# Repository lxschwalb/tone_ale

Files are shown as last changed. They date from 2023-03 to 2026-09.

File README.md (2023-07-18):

# Tone Ale
Reprogrammable rp2040 based guitar pedal with capacitive touch sensing. Some effects are toggled on and off by tapping on the pedal surface, others act as expression pedals by increasing and decreasing the pressure/surface area you apply to the pedal.

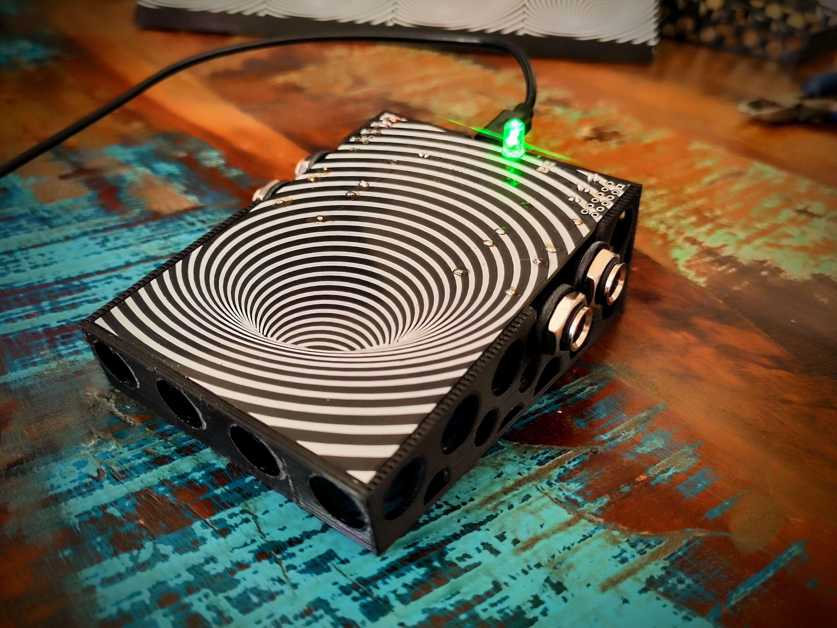
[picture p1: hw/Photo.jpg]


## Effects:
* audio interface
  * 2 input 2 output usb audio interface. Tap on pedal surface to mute/unmute it. LED indicates mute status. Only 48kHz 32bit audio supported.
* cabinet simulator
  * Guitar cabinet simulator using an impulse response.
* delay
  * Stereo digital delay. Each repeat is half the volume of the previous. Set feedback to false for only one repeat. Change delay buffer size for a different delay time. set it to an odd number for ping pong delay.
* fuzz
  * Simple fuzz. Turn on the gate for a tight velcro sound. Change the gain and clipping levels to taste.
* low pass filter
  * Always on low pass filter. Cuttoff frequency is determined by pressure applied to pedal. When not touching the pedal the cuttoff frequency should be higher than audible range so it is as if there is no filter.
* phaser
  * phaser effect with various parameters that can be tuned in code.
* rig
  * fuzz and cabinet simulator together in one effect which kind of gives the sound of a full guitar rig.
* sample player (amen beat)
  * sample starts playing when you place your foot on the pedal and stops when you take it away. It restarts from the beginning everytime. Increasing and decreasing the pressure/surface area changes the volume.
* sample rate reducer
  * By default the sample rate is 48kH and there is no aliasing. By stepping on the pedal you decrease the sample rate and introduce aliasing artifacts. The harder you press the more the sample rate drops.
* unstable noise generator
  * Unstable IIR filter. It chaotically generates weird sounds which are effected by the input in unpredictable ways.
* vibrato
  * pitch shifting vibrato
* wah
  * classic band pass filter wah sound. It engages when you step on the pedal and then you control the wah using pressure. As soon as you remove your foot it outputs the dry signal again.
* wavefolder
  * Similar to fuzz, except instead of clipping it folds the part of the signal above the threshold back down.

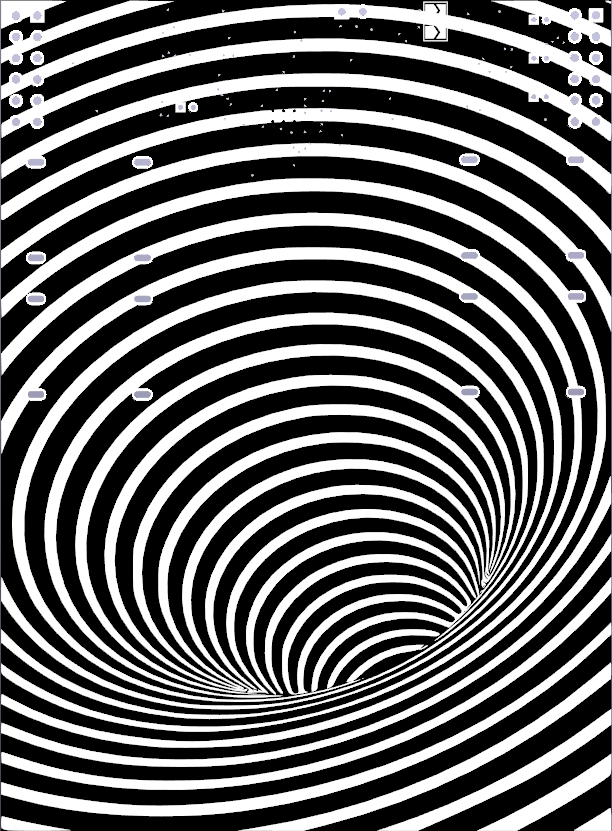
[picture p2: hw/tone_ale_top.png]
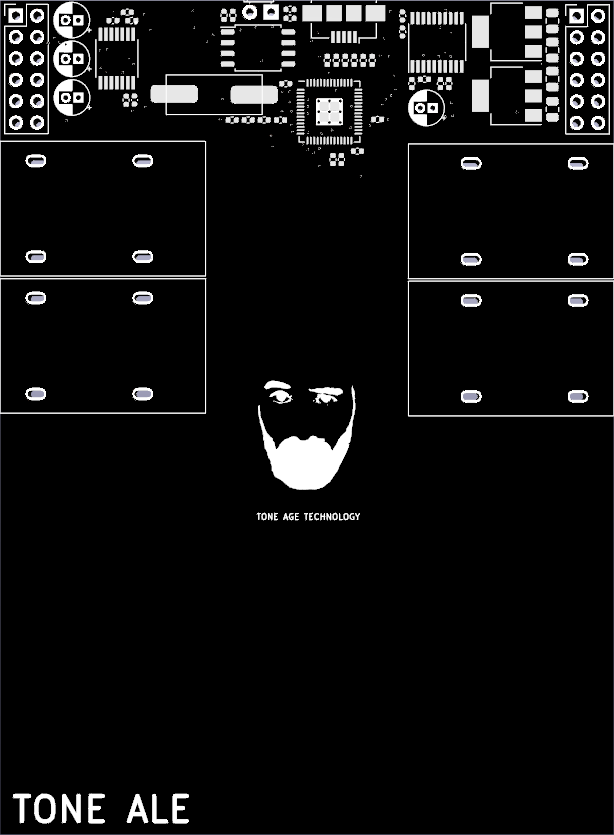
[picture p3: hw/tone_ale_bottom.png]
 

## Where to get one?
Everything necesary to build your own Tone Ale is available on this repository, but if you want to buy a fully assembled Pedal send an email to toneagetechnology@gmail.com. Profits are donated to effective charities.

Pedals will be sold for CHF125. In spirit of full transparency, I will share that my production cost per pedal is between CHF20 and CHF30 depending on a few varying factors. It would likely cost you more. It's cheaper for me since I'm producing it in bulk and already have a lot of the tools required. I will assume it's a fixed CHF25 and donate CHF100 for every pedal sold. This production cost does not include my time/labour, because that is done pro bono.

For questions about my charity selection process, motivation for doing this, or if you have a prefered charity you want payment for your pedal donated to, you can also email toneagetechnology@gmail.com.

## Upload new effect
You don't need to be able to develop or install special software to upload new effects. All you need is a usb port, cable, and something conductive (a piece of tin foil will to).

To upload new effects, connect the pedal to a computer with a usb cable, touch the part of the pcb shown in the image below with a piece of tin foil and drag it to the side as shown. Now the pedal shows up as a mass storage device. Just drag and drop the uf2 file(found in /compiled_effects) of the corresponding effect and you're all set to go.

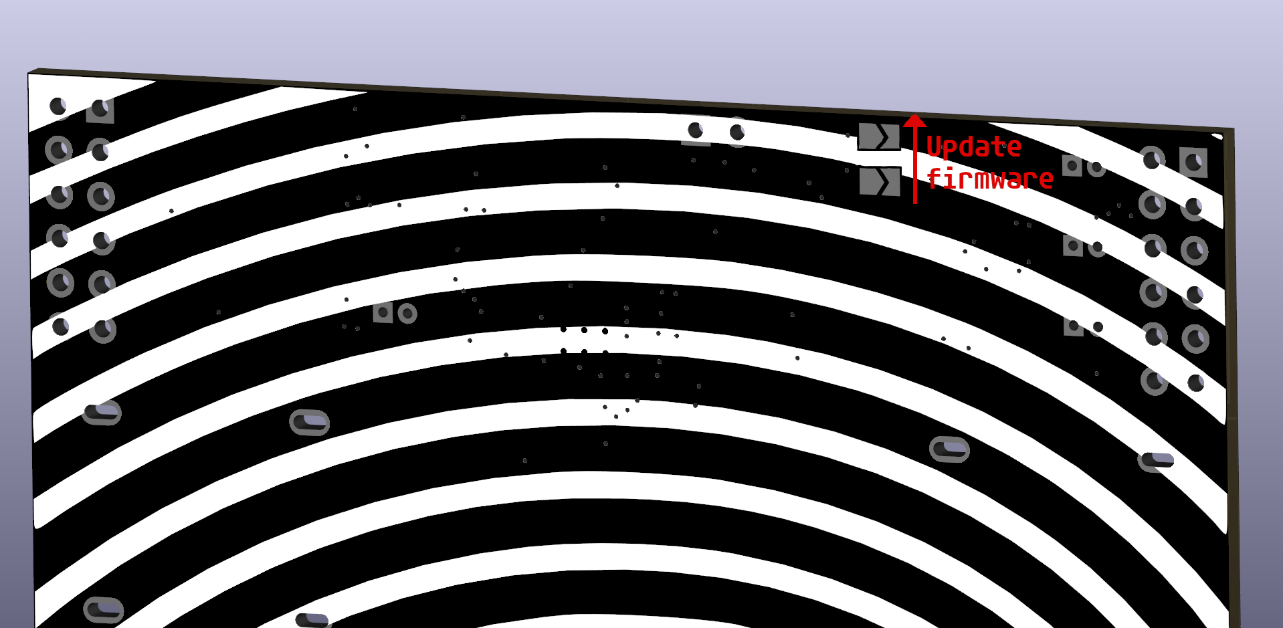
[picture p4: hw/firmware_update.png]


## Compile effects
Perhaps you want to alter some effects before uploading it onto the pedal. For example you might want to increase the gain of the fuzz. This would require recompiling the effect after the changes to the code have been made. Follow the steps below to recompile:

First set up the Pi Pico SDK according to [this guide](https://www.raspberrypi.com/documentation/microcontrollers/c_sdk.html#sdk-setup)

Open terminal in the main project folder (called tone_ale) and run the following commands:

`cp <pico_sdk_path>/external/pico_sdk_import.cmake .` (replace <pico_sdk_path> with wherever you set up the SDK)

`cd /build`

`cmake ..`

`make`

This will compile each effect and place it in "/build/<effect_name>/<effect_name>.uf2". This uf2 file can then directly be uploaded onto the pedal using the method descibed above

## Develop new effects
TODO explain this

## Pinout
The pinout is shown below.
* POT0, POT1, POT2 and POT3 can be programmed as analog inputs, so they can be used for adding potentiometers (knobs)
* GP0, GP1, GP2, GP3, GP4, GP5 and GP6 are general purpose digital input/output pins, so they can be used for many different things including LEDs, buttons, digitally communicating with external devices such as displays etc.
* If you want to chain multiple Tone Ale's together, you can reduce cost and improve fidelity by not putting DACs and ADCs between them and just directly connect their VBUS, GND, I2CV_CLK, I2CV_WS and connect the I2CV_OUT from the first pedal to the I2CV_IN of the second. You can chain many pedals together in this way (it's been tested up to 4). NB: Only the first pedal in the chain should have an PCM1808 soldered on, otherwise the I2CV_CLK and I2CV_WS will be driven by multiple sources. Alternatively you can run a different firmware on all pedals except the first one in the chain where the PCM1808 does not generate a clock. (TODO: explain how to do this)

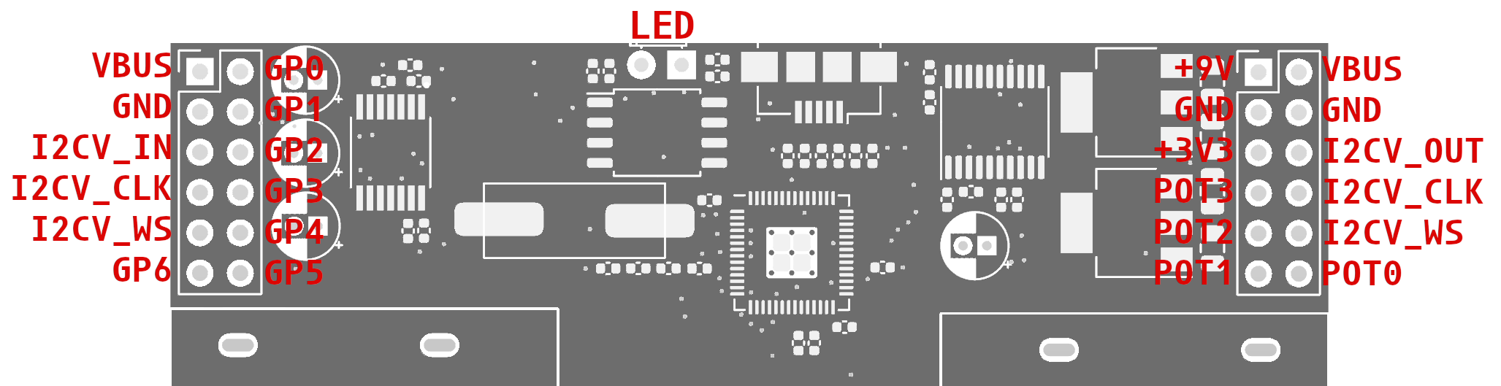
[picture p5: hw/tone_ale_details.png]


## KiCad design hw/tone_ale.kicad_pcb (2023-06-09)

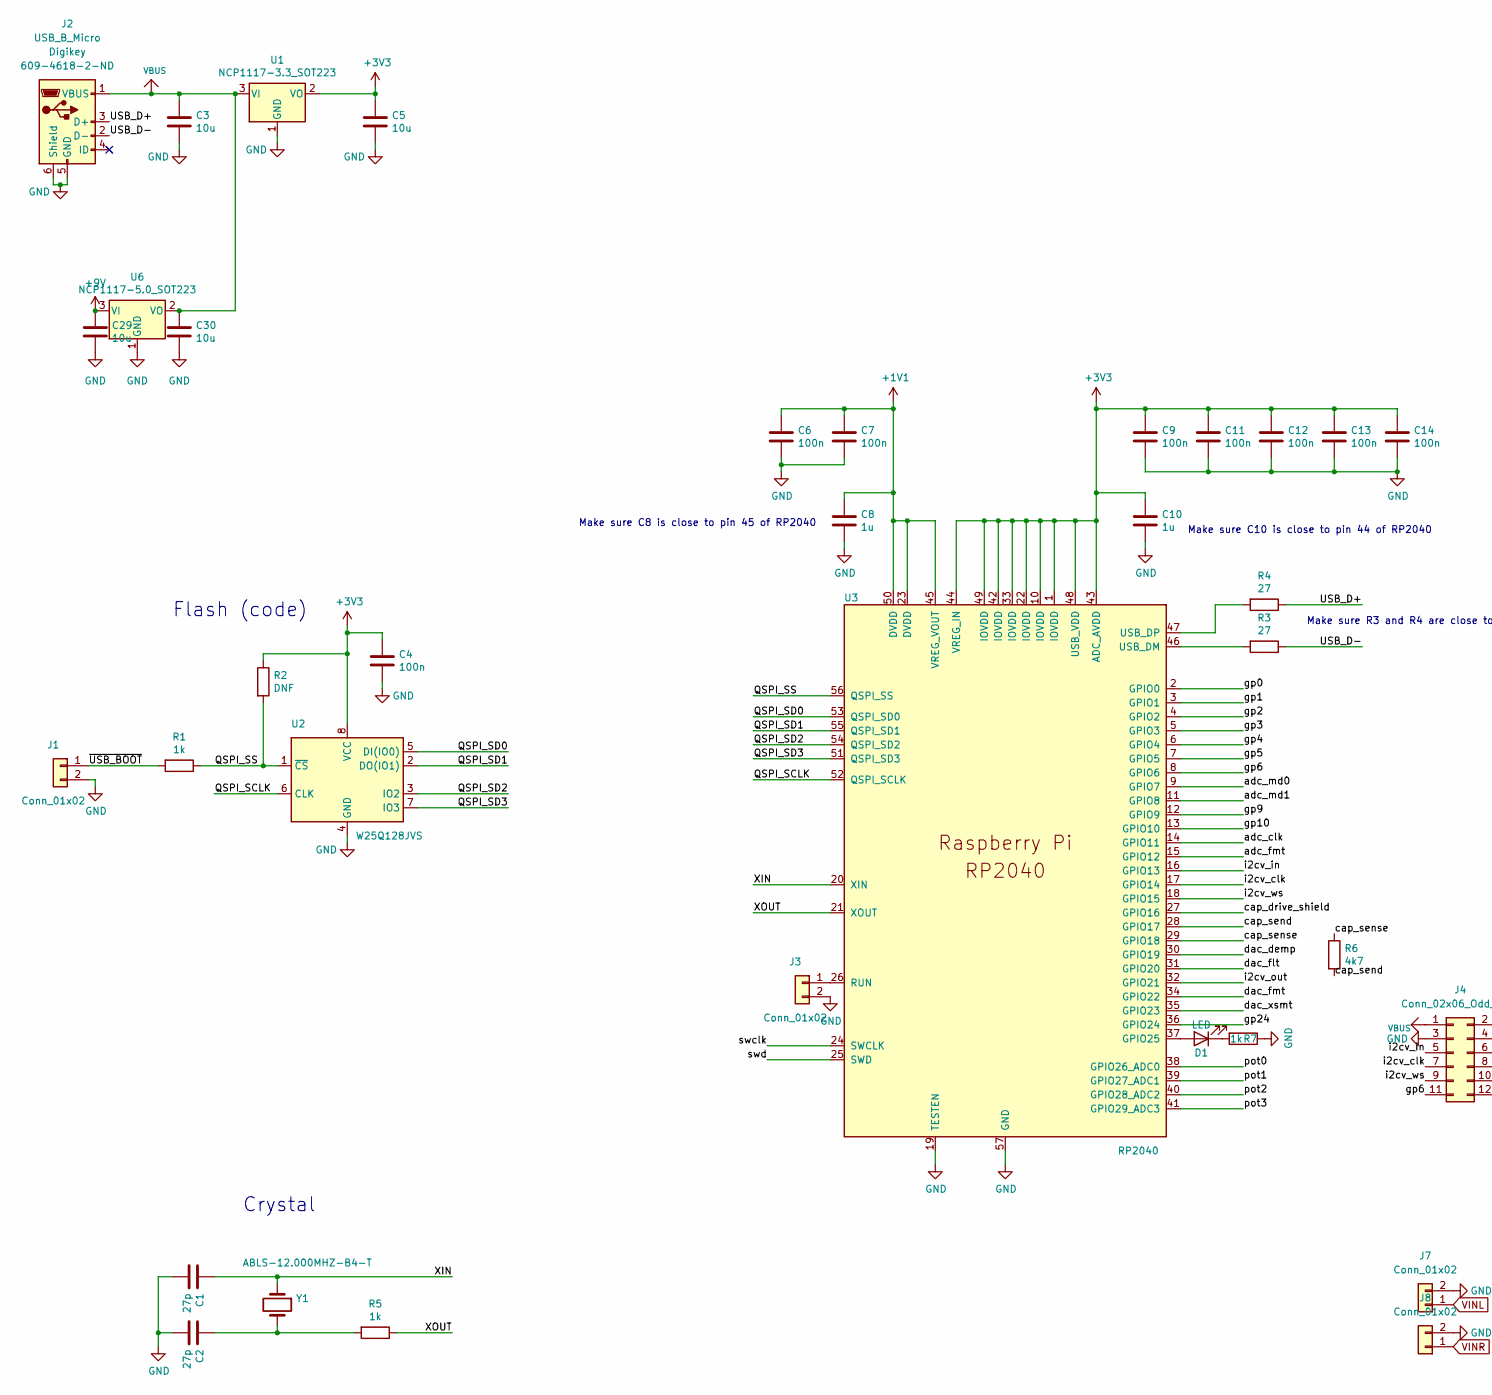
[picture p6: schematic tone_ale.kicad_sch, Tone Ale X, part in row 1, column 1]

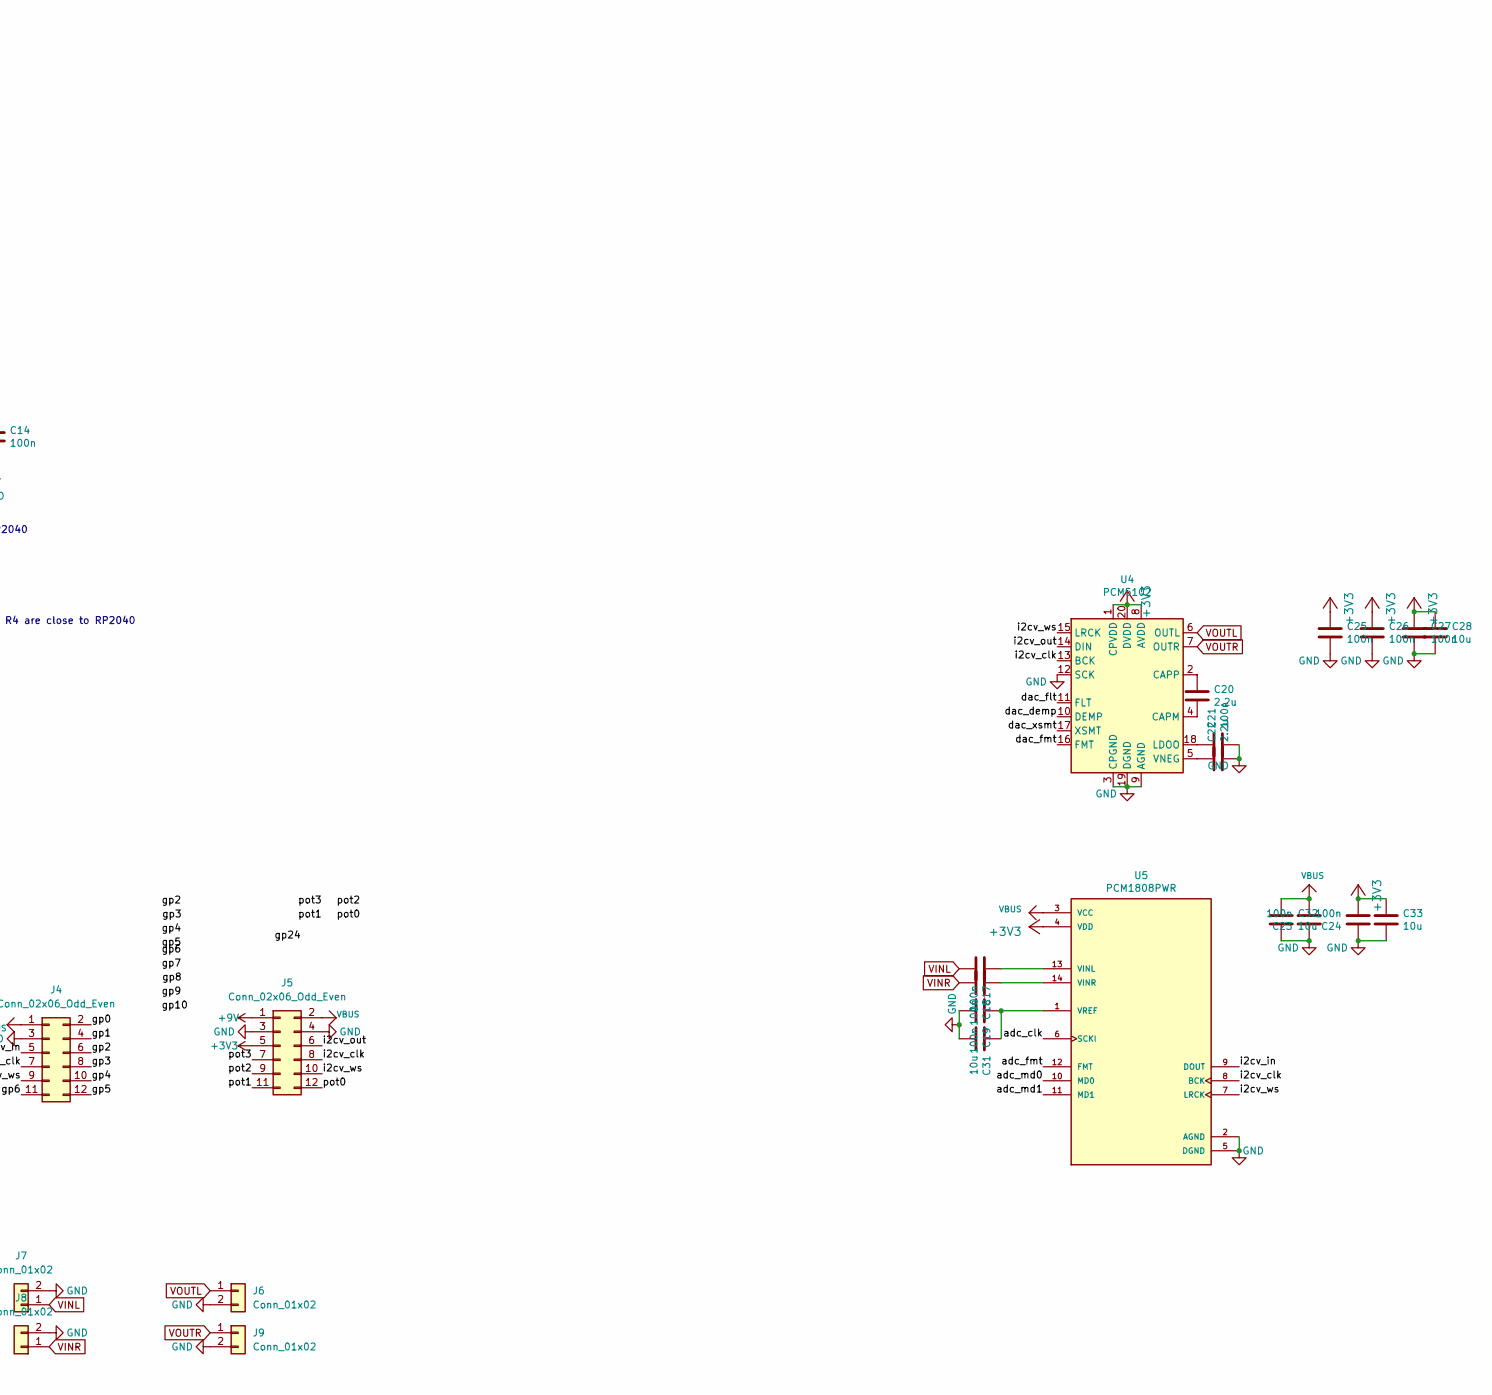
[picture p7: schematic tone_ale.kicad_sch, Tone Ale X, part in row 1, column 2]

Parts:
C1, C2: 27p; C_0402_1005Metric
C3, C5, C29, C30: 10u; C_0805_2012Metric
C4, C6, C7, C9, C11, C12, C13, C14, C17, C18, C19, C21, C23, C24, C25, C26, C27: 100n; C_0402_1005Metric
C8, C10: 1u; C_0402_1005Metric
C20, C22: 2.2u; C_0402_1005Metric
C28, C31, C32, C33: 10u; CP_Radial_D4.0mm_P1.50mm
D1: LED; LED_D3.0mm_Horizontal_O1.27mm_Z2.0mm
J1, J3: Conn_01x02; SolderJumper-2_P1.3mm_Open_TrianglePad1.0x1.5mm
J2: USB_B_Micro; USB_Micro-B_Amphenol_10104110_Horizontal
J4, J5: Conn_02x06_Odd_Even; PinHeader_2x06_P2.54mm_Vertical
J6, J7, J8, J9: Conn_01x02; acjm_mhdr
R1, R5, R7: 1k; C_0402_1005Metric
R2: DNF; C_0402_1005Metric
R3, R4: 27; C_0402_1005Metric
R6: 4k7; C_0402_1005Metric
U1: NCP1117-3.3_SOT223; SOT-223-3_TabPin2
U2: W25Q128JVS; SOIC-8_5.23x5.23mm_P1.27mm; Part Nr W25Q128JVSIMTR (digikey)
U3: RP2040; RP2040-QFN-56; Part Nr 2648-SC0914(13)TR-ND
U4: PCM5102; TSSOP-20_4.4x6.5mm_P0.65mm
U5: PCM1808PWR; SOP65P640X120-14N; PARTREV B
U6: NCP1117-5.0_SOT223; SOT-223-3_TabPin2
Y1: ABLS-12.000MHZ-B4-T; ABLS_crystal_12.7x04.7; Part Nr 535-10218-2-ND (digikey)

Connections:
+1V1: C6.1, C7.1, C8.1, U3.23 (DVDD), U3.45 (VREG_VOUT), U3.50 (DVDD)
+3V3: C4.1, C5.1, C9.1, C10.1, C11.1, C12.1, C13.1, C14.1, C24.2, C25.1, C26.1, C27.1, C28.1, C33.1, J5.5, R2.1, U1.2 (VO), U2.8 (VCC), U3.1 (IOVDD), U3.10 (IOVDD), U3.22 (IOVDD), U3.33 (IOVDD), U3.42 (IOVDD), U3.43 (ADC_AVDD), U3.44 (VREG_IN), U3.48 (USB_VDD), U3.49 (IOVDD), U4.1 (CPVDD), U4.8 (AVDD), U4.20 (DVDD), U5.4 (VDD)
+9V: C29.1, J5.1, U6.3 (VI)
/QSPI_SCLK: U2.6 (CLK), U3.52 (QSPI_SCLK)
/QSPI_SD0: U2.5 (DI(IO0)), U3.53 (QSPI_SD0)
/QSPI_SD1: U2.2 (DO(IO1)), U3.55 (QSPI_SD1)
/QSPI_SD2: U2.3 (IO2), U3.54 (QSPI_SD2)
/QSPI_SD3: U2.7 (IO3), U3.51 (QSPI_SD3)
/QSPI_SS: R1.1, R2.2, U2.1 (~CS), U3.56 (QSPI_SS)
/USB_D+: J2.3 (D+), R4.1
/USB_D-: J2.2 (D-), R3.1
/XIN: C1.1, U3.20 (XIN), Y1.1
/XOUT: R5.1, U3.21 (XOUT)
/adc_clk: U3.14 (GPIO11), U5.6 (SCKI)
/adc_fmt: U3.15 (GPIO12), U5.12 (FMT)
/adc_md0: U3.9 (GPIO7), U5.10 (MD0)
/adc_md1: U3.11 (GPIO8), U5.11 (MD1)
/cap_drive_shield: U3.27 (GPIO16)
/cap_send: R6.2, U3.28 (GPIO17)
/cap_sense: R6.1, U3.29 (GPIO18)
/dac_demp: U3.30 (GPIO19), U4.10 (DEMP)
/dac_flt: U3.31 (GPIO20), U4.11 (FLT)
/dac_fmt: U3.34 (GPIO22), U4.16 (FMT)
/dac_xsmt: U3.35 (GPIO23), U4.17 (XSMT)
/gp0: J4.2, U3.2 (GPIO0)
/gp1: J4.4, U3.3 (GPIO1)
/gp2: J4.6, U3.4 (GPIO2)
/gp3: J4.8, U3.5 (GPIO3)
/gp4: J4.10, U3.6 (GPIO4)
/gp5: J4.12, U3.7 (GPIO5)
/gp6: J4.11, U3.8 (GPIO6)
/gp9: U3.12 (GPIO9)
/gp10: U3.13 (GPIO10)
/gp24: U3.36 (GPIO24)
/i2cv_clk: J4.7, J5.8, U3.17 (GPIO14), U4.13 (BCK), U5.8 (BCK)
/i2cv_in: J4.5, U3.16 (GPIO13), U5.9 (DOUT)
/i2cv_out: J5.6, U3.32 (GPIO21), U4.14 (DIN)
/i2cv_ws: J4.9, J5.10, U3.18 (GPIO15), U4.15 (LRCK), U5.7 (LRCK)
/pot0: J5.12, U3.38 (GPIO26_ADC0)
/pot1: J5.11, U3.39 (GPIO27_ADC1)
/pot2: J5.9, U3.40 (GPIO28_ADC2)
/pot3: J5.7, U3.41 (GPIO29_ADC3)
/swclk: U3.24 (SWCLK)
/swd: U3.25 (SWD)
/~USB_BOOT: J1.1, R1.2
GND: C1.2, C2.2, C3.2, C4.2, C5.2, C6.2, C7.2, C8.2, C9.2, C10.2, C11.2, C12.2, C13.2, C14.2, C19.2, C21.2, C22.2, C23.1, C24.1, C25.2, C26.2, C27.2, C28.2, C29.2, C30.2, C31.2, C32.2, C33.2, J1.2, J2.5 (GND), J2.6 (Shield), J3.2, J4.3, J5.3, J5.4, J6.2, J7.2, J8.2, J9.2, R7.1, U1.1 (GND), U2.4 (GND), U3.19 (TESTEN), U3.57 (GND), U4.3 (CPGND), U4.9 (AGND), U4.12 (SCK), U4.19 (DGND), U5.2 (AGND), U5.5 (DGND), U6.1 (GND)
unnamed: C2.1, R5.2, Y1.2
unnamed: C17.1, U5.13 (VINL)
unnamed: C18.1, U5.14 (VINR)
unnamed: C19.1, C31.1, U5.1 (VREF)
unnamed: C20.1, U4.2 (CAPP)
unnamed: C20.2, U4.4 (CAPM)
unnamed: C21.1, U4.18 (LDOO)
unnamed: C22.1, U4.5 (VNEG)
unnamed: D1.1 (K), R7.2
unnamed: D1.2 (A), U3.37 (GPIO25)
unnamed: J3.1, U3.26 (RUN)
unnamed: R3.2, U3.46 (USB_DM)
unnamed: R4.2, U3.47 (USB_DP)
VBUS: C3.1, C23.2, C30.1, C32.1, J2.1 (VBUS), J4.1, J5.2, U1.3 (VI), U5.3 (VCC), U6.2 (VO)
VINL: C17.2, J7.1
VINR: C18.2, J8.1
VOUTL: J6.1, U4.6 (OUTL)
VOUTR: J9.1, U4.7 (OUTR)

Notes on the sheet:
Flash (code)
Make sure R3 and R4 are close to RP2040
Crystal
Make sure C10 is close to pin 44 of RP2040
Make sure C8 is close to pin 45 of RP2040

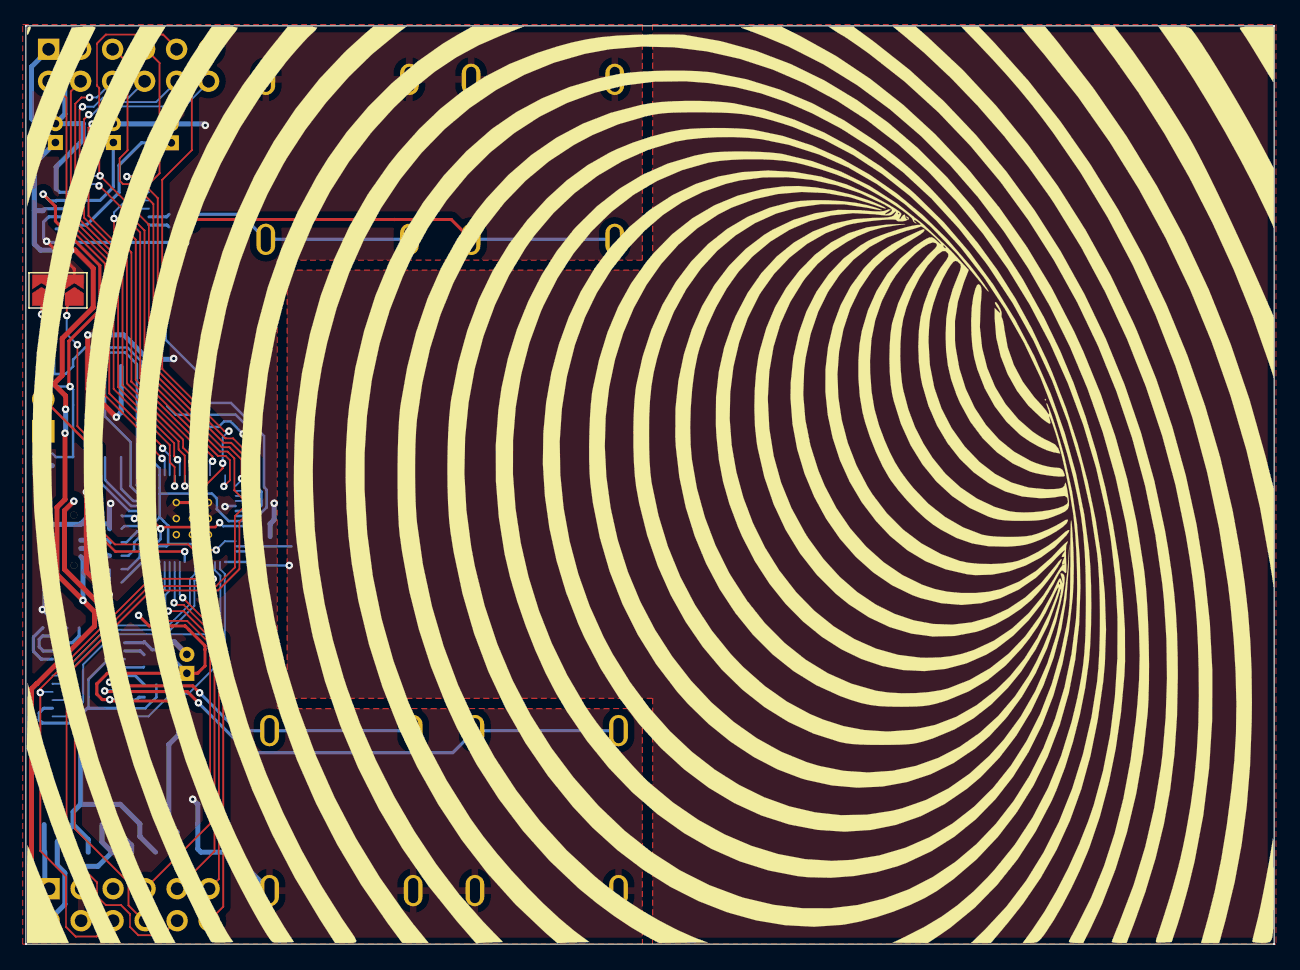
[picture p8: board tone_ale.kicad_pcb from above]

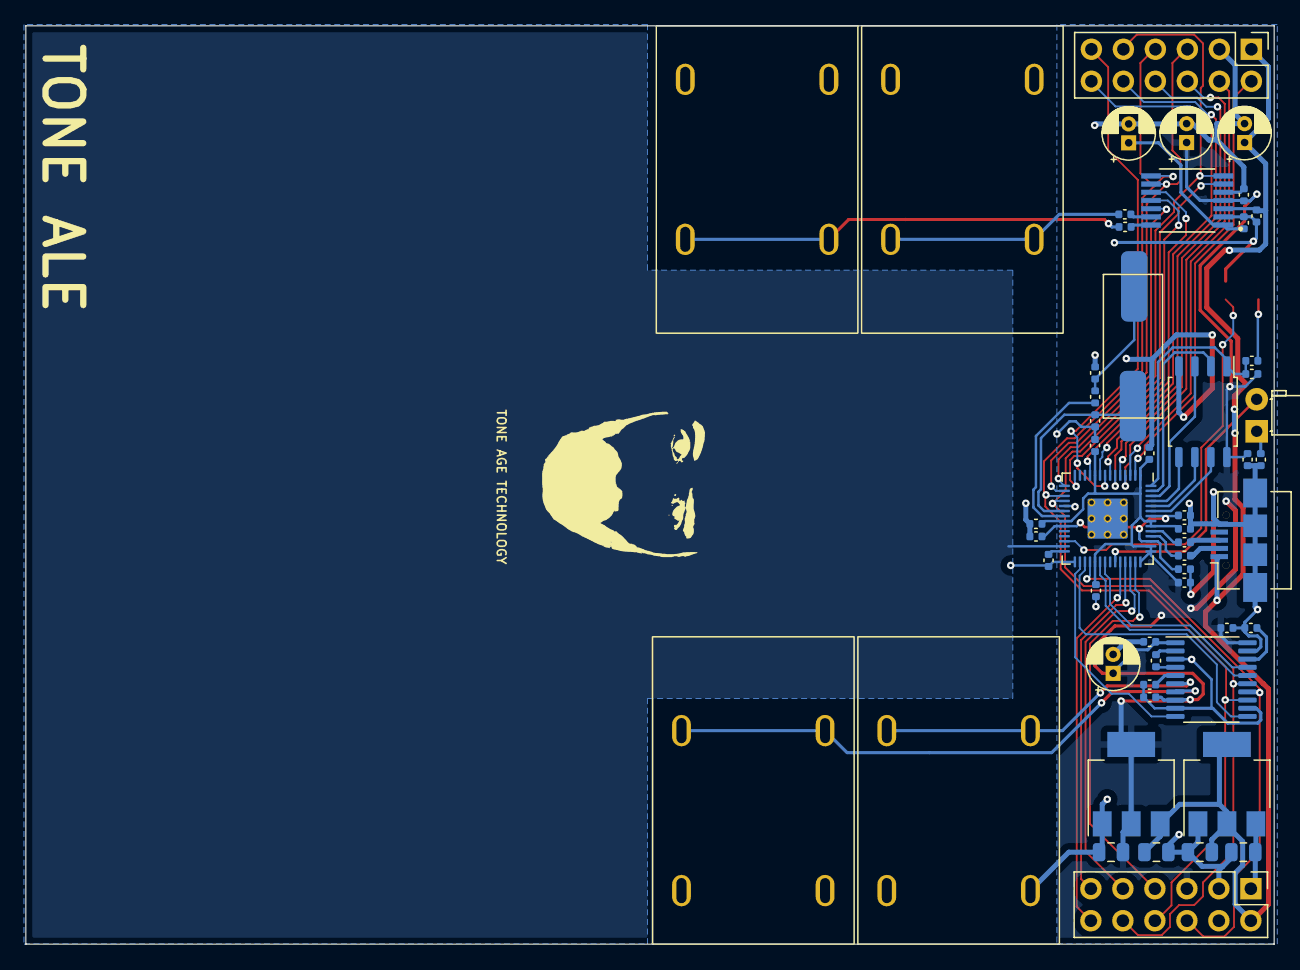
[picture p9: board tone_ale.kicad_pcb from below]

Board: 2 copper layers, 99.1 x 72.9 mm, 55 parts (53 on the bottom side), 58 nets.

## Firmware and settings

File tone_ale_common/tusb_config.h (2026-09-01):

/*
 * The MIT License (MIT)
 *
 * Copyright (c) 2020 Ha Thach (tinyusb.org)
 * Copyright (c) 2020 Jerzy Kasenberg
 *
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
 */

#ifndef _TUSB_CONFIG_H_
#define _TUSB_CONFIG_H_

// CFG_TUSB_DEBUG for debugging
// 0 : no debug
// 1 : print error
// 2 : print warning
// 3 : print info
#define CFG_TUSB_DEBUG 0

//--------------------------------------------------------------------
// COMMON CONFIGURATION
//--------------------------------------------------------------------

#include "pico/stdlib.h"

#define USB_VID         0xcafe
#define USB_PID_BASE    0x0000

// Unit numbers are arbitrary selected
#define UAC2_ENTITY_CLOCK               0x04
// Speaker path
#define UAC2_ENTITY_SPK_INPUT_TERMINAL  0x01
#define UAC2_ENTITY_SPK_OUTPUT_TERMINAL 0x03
// Microphone path
#define UAC2_ENTITY_MIC_INPUT_TERMINAL  0x11
#define UAC2_ENTITY_MIC_OUTPUT_TERMINAL 0x13

enum
{
  ITF_NUM_AUDIO_CONTROL = 0,
  ITF_NUM_AUDIO_STREAMING_SPK,
  ITF_NUM_AUDIO_STREAMING_MIC,
  ITF_NUM_TOTAL
};

#define TUD_AUDIO_DESC_CTRL_LEN       \
  (                                   \
      TUD_AUDIO_DESC_CLK_SRC_LEN      \
    + TUD_AUDIO_DESC_INPUT_TERM_LEN   \
    + TUD_AUDIO_DESC_OUTPUT_TERM_LEN  \
    + TUD_AUDIO_DESC_INPUT_TERM_LEN   \
    + TUD_AUDIO_DESC_OUTPUT_TERM_LEN  \
  )

#define TUD_AUDIO_DESC_LEN              \
  (                                     \
      TUD_AUDIO_DESC_IAD_LEN            \
    + TUD_AUDIO_DESC_STD_AC_LEN         \
    + TUD_AUDIO_DESC_CS_AC_LEN          \
    + TUD_AUDIO_DESC_CTRL_LEN           \
    /* Interface 1, Alternate 0 */      \
    + TUD_AUDIO_DESC_STD_AS_INT_LEN     \
    /* Interface 1, Alternate 1 */      \
    + TUD_AUDIO_DESC_STD_AS_INT_LEN     \
    + TUD_AUDIO_DESC_CS_AS_INT_LEN      \
    + TUD_AUDIO_DESC_TYPE_I_FORMAT_LEN  \
    + TUD_AUDIO_DESC_STD_AS_ISO_EP_LEN  \
    + TUD_AUDIO_DESC_CS_AS_ISO_EP_LEN   \
    /* Interface 2, Alternate 0 */      \
    + TUD_AUDIO_DESC_STD_AS_INT_LEN     \
    /* Interface 2, Alternate 1 */      \
    + TUD_AUDIO_DESC_STD_AS_INT_LEN     \
    + TUD_AUDIO_DESC_CS_AS_INT_LEN      \
    + TUD_AUDIO_DESC_TYPE_I_FORMAT_LEN  \
    + TUD_AUDIO_DESC_STD_AS_ISO_EP_LEN  \
    + TUD_AUDIO_DESC_CS_AS_ISO_EP_LEN   \
  )

#define TUD_AUDIO_DESCRIPTOR(_stridx, _strid_rx, _strid_tx, _epout, _epin) \
    /* Standard Interface Association Descriptor (IAD) */\
    TUD_AUDIO_DESC_IAD(/*_firstitfs*/ ITF_NUM_AUDIO_CONTROL, /*_nitfs*/ ITF_NUM_TOTAL, /*_stridx*/ 0x00),\
    /* Standard AC Interface Descriptor(4.7.1) */\
    TUD_AUDIO_DESC_STD_AC(/*_itfnum*/ ITF_NUM_AUDIO_CONTROL, /*_nEPs*/ 0x00, /*_stridx*/ _stridx),\
    /* Class-Specific AC Interface Header Descriptor(4.7.2) */\
    TUD_AUDIO_DESC_CS_AC(/*_bcdADC*/ 0x0200, /*_category*/ AUDIO_USB_FUNC, /*_totallen*/ TUD_AUDIO_DESC_CTRL_LEN, /*_ctrl*/ AUDIO_CTRL_NONE << AUDIO_CS_AS_INTERFACE_CTRL_LATENCY_POS),\
    /* Clock Source Descriptor(4.7.2.1) */\
    /* Windows (usbaudio2.sys) requires the sample frequency control to be host-readable */\
    TUD_AUDIO_DESC_CLK_SRC(/*_clkid*/ UAC2_ENTITY_CLOCK, /*_attr*/ AUDIO_CLOCK_SOURCE_ATT_INT_FIX_CLK, /*_ctrl*/ (AUDIO_CTRL_RW << AUDIO_CLOCK_SOURCE_CTRL_CLK_FRQ_POS)|(AUDIO_CTRL_R << AUDIO_CLOCK_SOURCE_CTRL_CLK_VAL_POS), /*_assocTerm*/ 0x00,  /*_stridx*/ 0x00),    \
    /* Input Terminal Descriptor(4.7.2.4) */\
    TUD_AUDIO_DESC_INPUT_TERM(/*_termid*/ UAC2_ENTITY_SPK_INPUT_TERMINAL, /*_termtype*/ AUDIO_TERM_TYPE_USB_STREAMING, /*_assocTerm*/ 0x00, /*_clkid*/ UAC2_ENTITY_CLOCK, /*_nchannelslogical*/ CFG_TUD_AUDIO_FUNC_1_N_CHANNELS_SPK, /*_channelcfg*/ CFG_TUD_AUDIO_FUNC_1_ASSIGN_SPK, /*_idxchannelnames*/ 0x00, /*_ctrl*/ AUDIO_CTRL_NONE << AUDIO_IN_TERM_CTRL_CONNECTOR_POS, /*_stridx*/ 0x00),\
    /* Output Terminal Descriptor(4.7.2.5) */\
    /* Source directly from the input terminal - there is no feature unit descriptor, and Windows (usbaudio2.sys) rejects a topology referencing a missing entity */\
    TUD_AUDIO_DESC_OUTPUT_TERM(/*_termid*/ UAC2_ENTITY_SPK_OUTPUT_TERMINAL, /*_termtype*/ AUDIO_TERM_TYPE_OUT_GENERIC_SPEAKER, /*_assocTerm*/ 0x00, /*_srcid*/ UAC2_ENTITY_SPK_INPUT_TERMINAL, /*_clkid*/ UAC2_ENTITY_CLOCK, /*_ctrl*/ 0x0000, /*_stridx*/ 0x00),\
    /* Input Terminal Descriptor(4.7.2.4) */\
    TUD_AUDIO_DESC_INPUT_TERM(/*_termid*/ UAC2_ENTITY_MIC_INPUT_TERMINAL, /*_termtype*/ AUDIO_TERM_TYPE_IN_GENERIC_MIC, /*_assocTerm*/ 0x00, /*_clkid*/ UAC2_ENTITY_CLOCK, /*_nchannelslogical*/ CFG_TUD_AUDIO_FUNC_1_N_CHANNELS_MIC, /*_channelcfg*/ CFG_TUD_AUDIO_FUNC_1_ASSIGN_MIC, /*_idxchannelnames*/ 0x00, /*_ctrl*/ AUDIO_CTRL_NONE << AUDIO_IN_TERM_CTRL_CONNECTOR_POS, /*_stridx*/ 0x00),\
    /* Output Terminal Descriptor(4.7.2.5) */\
    TUD_AUDIO_DESC_OUTPUT_TERM(/*_termid*/ UAC2_ENTITY_MIC_OUTPUT_TERMINAL, /*_termtype*/ AUDIO_TERM_TYPE_USB_STREAMING, /*_assocTerm*/ 0x00, /*_srcid*/ UAC2_ENTITY_MIC_INPUT_TERMINAL, /*_clkid*/ UAC2_ENTITY_CLOCK, /*_ctrl*/ 0x0000, /*_stridx*/ 0x00),\
    /* Standard AS Interface Descriptor(4.9.1) */\
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

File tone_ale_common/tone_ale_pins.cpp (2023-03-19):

/**
 * Copyright (c) 2022 Tone Age Technology
 *
 * SPDX-License-Identifier: BSD-3-Clause
 */

#include <stdio.h>
#include "pico/stdlib.h"

#define LED_PIN         25
#define ADC_FMT_PIN     12
#define DAC_DEMP_PIN    19
#define DAC_FLT_PIN     20
#define DAC_FMT_PIN     22
#define DAC_XSMT_PIN    23

void tone_ale_pins_setup() {
    gpio_init(LED_PIN);
    gpio_init(ADC_FMT_PIN);
    gpio_init(DAC_DEMP_PIN);
    gpio_init(DAC_FLT_PIN);
    gpio_init(DAC_FMT_PIN);
    gpio_init(DAC_XSMT_PIN);

    gpio_set_dir(LED_PIN, GPIO_OUT);
    gpio_set_dir(ADC_FMT_PIN, GPIO_OUT);
    gpio_set_dir(DAC_DEMP_PIN, GPIO_OUT);
    gpio_set_dir(DAC_FLT_PIN, GPIO_OUT);
    gpio_set_dir(DAC_FMT_PIN, GPIO_OUT);
    gpio_set_dir(DAC_XSMT_PIN, GPIO_OUT);

    gpio_put(LED_PIN, 1);
    gpio_put(ADC_FMT_PIN, 0);
    gpio_put(DAC_DEMP_PIN, 0);
    gpio_put(DAC_FLT_PIN, 1);
    gpio_put(DAC_FMT_PIN, 0);
    gpio_put(DAC_XSMT_PIN, 1);
}

void set_led(bool state){
    gpio_put(LED_PIN, state);
}

bool get_led(){
    return gpio_get(LED_PIN);
}

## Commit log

2023-03-12 added samplerate_reducer and associated functionality to capsense
2023-06-09 Updated hardware. Made wah only engaged while foot is on pedal
    [tone_ale.kicad_pcb, tone_ale.kicad_sch]
2023-06-10 Fixed channel alignment to be more robust and deterministic
    [tone_ale_i2cv.cpp]
2023-06-12 Fixed delay and added amen_beat
    [tone_ale_i2cv.cpp]
2023-07-14 Made capacitive sensor self calibrate. Added compiled effects
